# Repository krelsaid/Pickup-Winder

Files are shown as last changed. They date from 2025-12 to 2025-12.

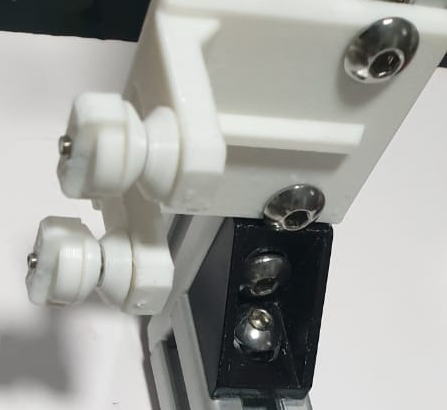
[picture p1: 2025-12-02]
picture/Image 3.png

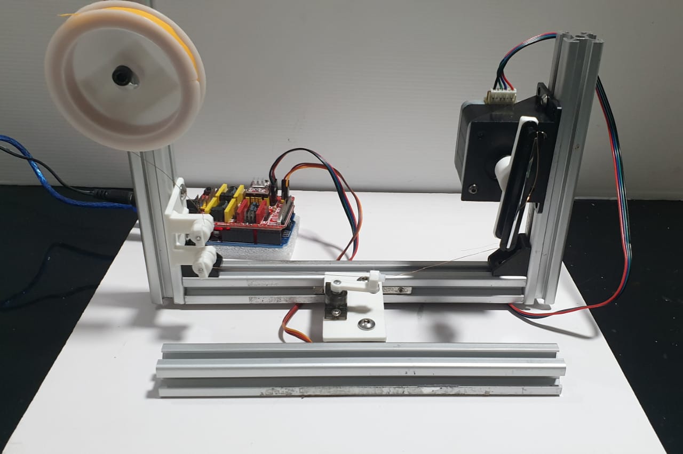
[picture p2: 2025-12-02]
picture/Image 1.jpeg

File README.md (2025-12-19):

# Guitar Pickup Winder Controller

A desktop application for controlling a DIY guitar pickup winder, featuring a real-time visualization of the winding process. Built with Python and PyQt6.

## Table of Contents

- [Overview](#overview)
- [Features](#features)
- [Core Component: The Winder Widget](#core-component-the-winder-widget)
- [How It Works](#how-it-works)
- [Hardware & Firmware Controller (Arduino Uno)](#hardware--firmware-controller-arduino-uno)
- [Dependencies](#dependencies)
- [Setup and Installation](#setup-and-installation)
- [Usage](#usage)
- [Future Development](#future-development)
- [Contributing](#contributing)

## Overview

This project is the software controller for a homemade guitar pickup winder. Winding pickups requires precise control over the number of turns and the distribution of the copper wire across the bobbin. This application provides a graphical user interface (GUI) to:

1.  **Configure** winding parameters (e.g., bobbin dimensions, target turns).
2.  **Control** the winder's motors (stepper for rotation, servo for wire guide).
3.  **Monitor** the winding process in real-time with a detailed visual representation.

The heart of the user interface is the `WinderWidget`, a custom PyQt6 widget that displays a dynamic cross-section of the pickup bobbin as it's being wound.

## Features

- **Graphical User Interface**: Easy-to-use interface built with PyQt6.
- **Real-time Winding Visualization**:
    - Displays a cross-section of the bobbin.
    - Shows the wire guide (servo) position.
    - Visualizes the wire building up in layers.
    - Renders dimension lines for bobbin length and height.
- **Configurable Winding Parameters**:
    - Bobbin Length & Height
    - Wire Diameter
    - Target Number of Turns
    - Turns Per Layer
    - Servo Travel Limits (Min/Max Angle)
- **Live Progress Tracking**: See the current turn count and its relation to the target.
- **Accurate Layer Simulation**: The visualization correctly models the back-and-forth traversal of the wire guide for each layer.

## Core Component: The Winder Widget

The file `winder_widget.py` contains the `WinderWidget` class, which is responsible for all the graphics.

### How it Renders:

1.  **Bobbin**: Draws a brown, T-shaped cross-section representing the bobbin's top and bottom flanges. The drawing is scaled to fit the widget's size.
2.  **Wire Guide**: A cyan line and circle at the top represent the wire guide, which is controlled by a servo. Its horizontal position is calculated based on the winding progress.
3.  **Winding Progress (`pos_ratio`)**: The widget calculates a `pos_ratio` (a value from 0.0 to 1.0) that represents the guide's position across the bobbin. It intelligently determines the direction of travel:
    - On even-numbered layers (0, 2, 4...), it moves from left to right (0.0 → 1.0).
    - On odd-numbered layers (1, 3, 5...), it moves from right to left (1.0 → 0.0).
4.  **Wire Buildup**: As the winding progresses, the widget draws vertical "gold" lines to represent the strands of wire. A new line is added only when the guide has moved a distance equivalent to one wire diameter, creating a realistic depiction of the coil.
5.  **Live Wire**: A single line is drawn from the wire guide down to the bobbin, showing the path of the wire currently being laid.

## How It Works

The application operates on a simple but effective principle:

1.  **User Input**: The user enters the physical characteristics of their pickup bobbin and the desired number of turns into the GUI.
2.  **Calculation**: The software calculates the number of turns that will fit in a single layer (`turns_per_layer`).
3.  **Motor Control**:
    - A **stepper motor** is commanded to turn the bobbin. It counts each rotation.
    - A **servo motor** is used to move the wire guide back and forth across the bobbin's length.
4.  **Synchronization**: The application synchronizes the servo's position with the stepper's turn count. The `pos_ratio` from the widget is mapped to the servo's angular range (`servo_min_angle` to `servo_max_angle`) and sent to the physical controller (e.g., an Arduino or ESP32).
5.  **Feedback**: The `WinderWidget` receives live data (current turns, servo position) from the controller part of the application and updates the display, giving the user immediate visual feedback.

## Hardware & Firmware Controller (Arduino Uno)

The Python application acts as the "brain," but the Arduino Uno is the "muscle," responsible for the real-time control of the motors.

### Role of the Firmware

- **Receives Commands**: Listens for commands sent over the serial port from the Python GUI (e.g., start/stop winding, set parameters).
- **Controls Motors**:
    - **Stepper Motor**: Precisely rotates the pickup bobbin. It uses a library like `AccelStepper` for smooth acceleration and constant speed.
    - **Servo Motor**: Moves the wire guide back and forth. Its position is updated continuously based on the winding progress.
- **Sends Feedback**: Reports the current turn count and status back to the Python application for live monitoring.

### Required Hardware

- **Microcontroller**: Arduino Uno.
- **Stepper Motor Driver**: A4988 or DRV8825. These drivers are ideal for controlling a stepper motor with an Arduino.
- **Stepper Motor**: NEMA 17 is a popular size for this application.
- **Servo Motor**: A standard SG90 micro servo is sufficient, but a more robust metal-gear servo (like an MG996R) is recommended for durability.

### Serial Communication Protocol

A simple text-based protocol is used for communication between the PC and the microcontroller.

**Commands from PC to Arduino (sent from Python):**

- `START:<target_turns>:<servo_min>:<servo_max>`: Starts the winding process.
    - Example: `START:8000:70:100`
- `STOP`: Immediately halts the winding process.
- `RESET`: Resets the turn counter to zero.

**Feedback from Arduino to PC (read by Python):**

- `TURN:<count>`: Reports the current number of turns.
    - Example: `TURN:1234`
- `STATUS:<message>`: Reports the current state.
    - Examples: `STATUS:IDLE`, `STATUS:WINDING`, `STATUS:DONE`

### Firmware Setup

1.  **Install Arduino IDE or PlatformIO**: Choose your preferred development environment.
2.  **Install Libraries**: From the library manager, install:
    - `AccelStepper` (by Mike McCauley)
    - `Servo` (usually built-in)
3.  **Configure Pins**: Open the `.ino` sketch and modify the pin definitions at the top of the file to match your hardware wiring.
4.  **Upload**: Compile and upload the sketch to your microcontroller board.

## Dependencies

This project requires Python 3 and the following library:

- **PyQt6**: For the graphical user interface.

```bash
pip install PyQt6
pip install pyserial
```

The physical winder itself would likely be controlled by a microcontroller (like an Arduino or ESP32) running its own firmware, communicating with this Python application over a serial port.

## Setup and Installation

1.  **Clone the repository:**
    ```bash
    git clone https://github.com/krelsaid/Pickup-Winder.git
    cd pickup-winder
    ```

2.  **Install dependencies:**
    ```bash
    pip install -r requirements.txt
    ```
    *(Note: You may need to create a `requirements.txt` file containing `PyQt6`)*

## Usage

1.  Run the main application file:
    ```bash
    python main_window.py
    ```
    *(Assuming the main entry point is `main_window.py`)*

2.  Connect to the winder hardware via the appropriate serial port in the GUI.
3.  Enter your bobbin and wire specifications in the settings panel.
4.  Set the target number of turns.
5.  Click the "Start Winding" button to begin the process.
6.  Monitor the progress on the visualization widget.

## Future Development

- [ ] Implement serial communication to control an Arduino/ESP32.
- [ ] Add presets for common pickup types (Strat, Tele, P-90, Humbucker).
- [ ] Add scatter winding options for a more "hand-wound" sound.
- [ ] Graph winding tension if a load cell is added to the hardware.
- [ ] Save and load winding job configurations to a file.

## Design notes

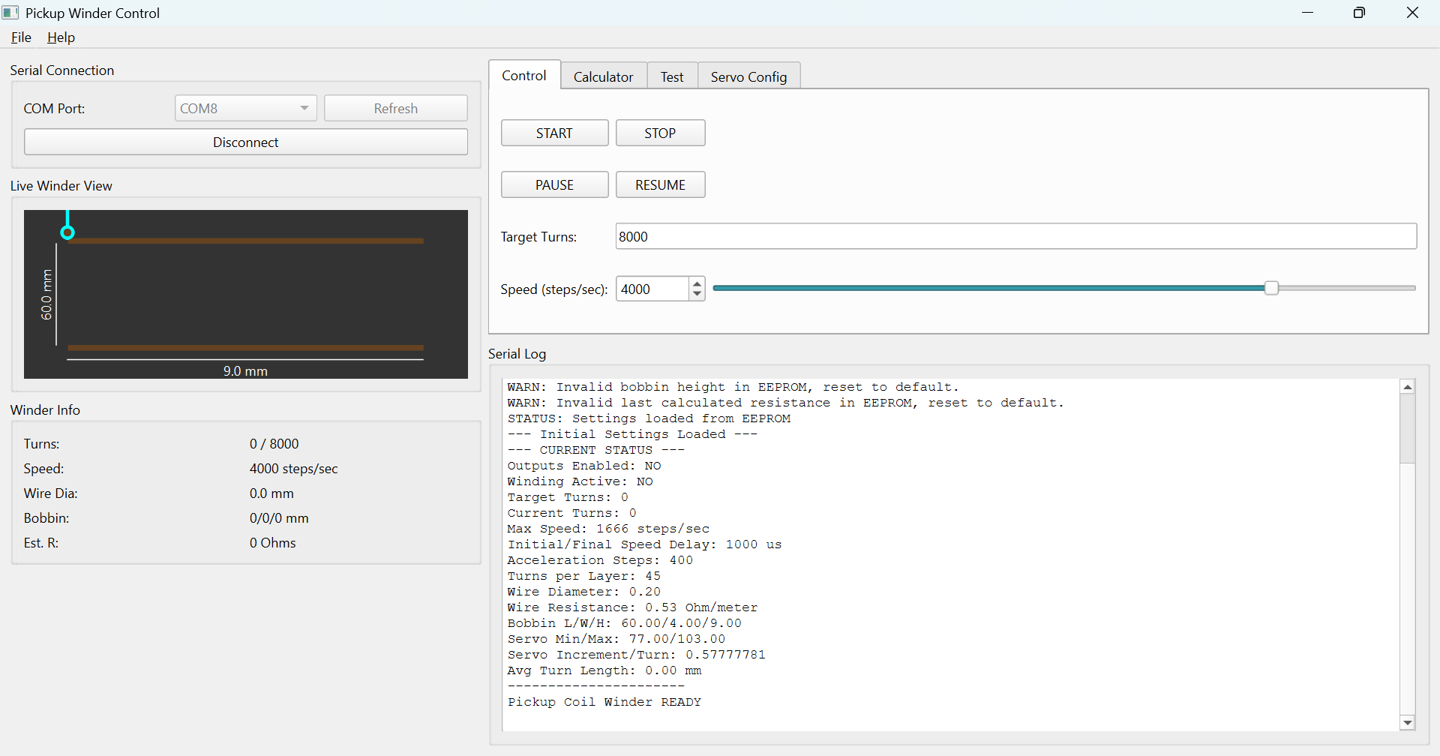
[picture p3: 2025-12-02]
picture/Guitar Pickup Winder Controller GUI.png

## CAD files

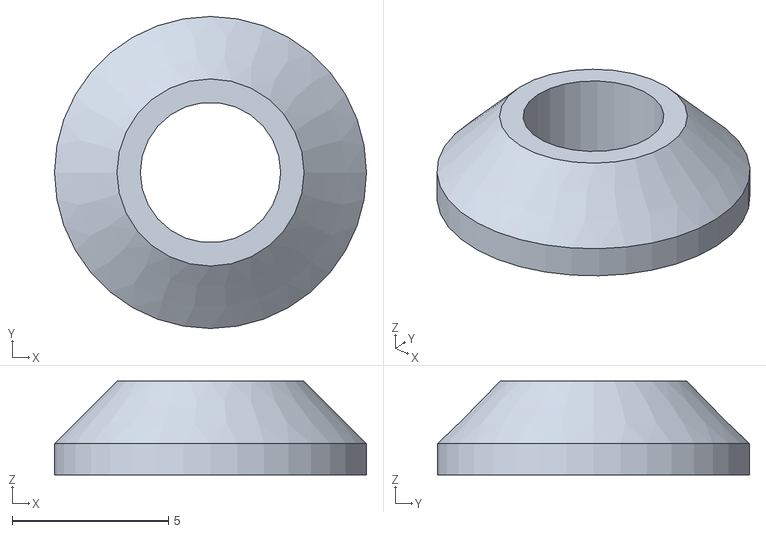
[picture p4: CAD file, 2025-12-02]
stl/spool clamp.stl
10.0 x 10.0 x 3.00

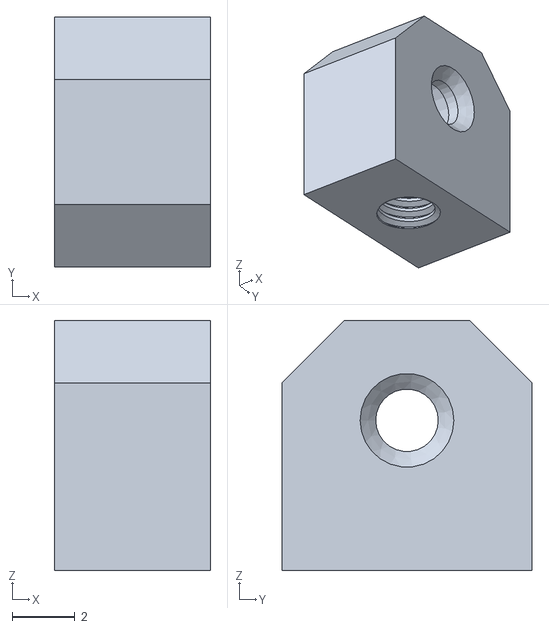
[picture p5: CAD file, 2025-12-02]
stl/lever_head.stl
5.00 x 8.00 x 8.00

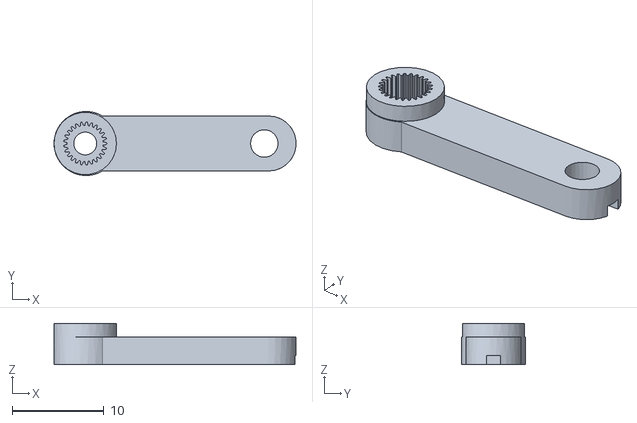
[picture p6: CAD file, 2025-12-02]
stl/servo lever.stl
26.4 x 6.99 x 4.50

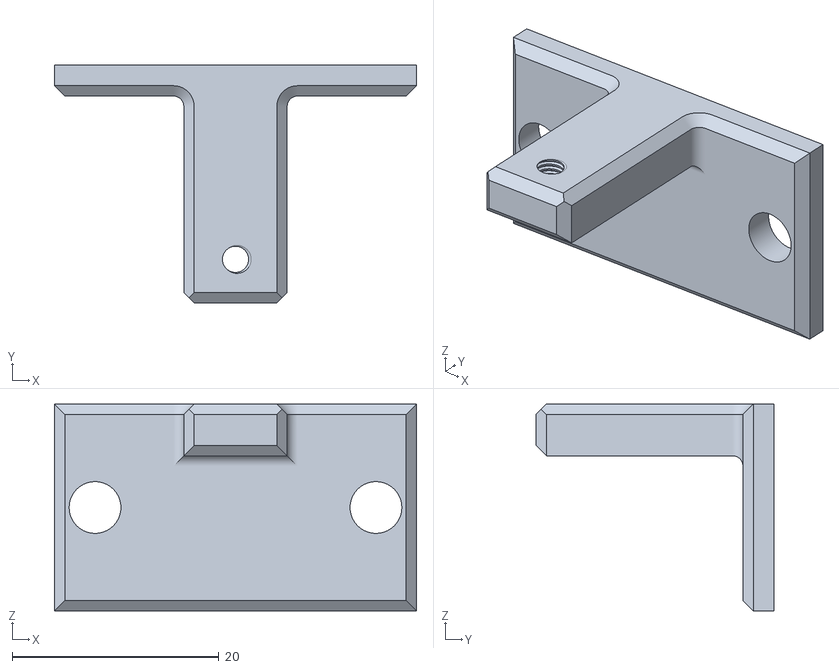
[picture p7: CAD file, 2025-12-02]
stl/spool clamp mount single.stl
35.0 x 23.0 x 20.0

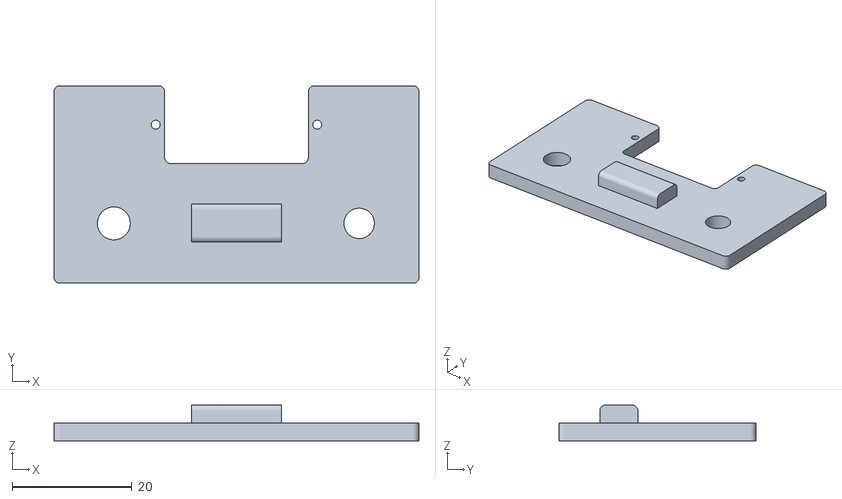
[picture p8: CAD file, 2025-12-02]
stl/servo_mount.stl
61.0 x 33.0 x 6.00

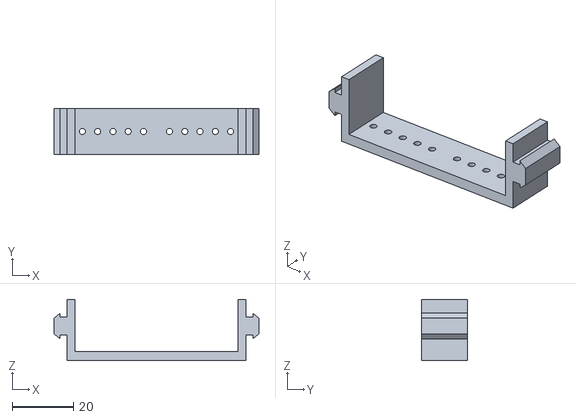
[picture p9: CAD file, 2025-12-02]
stl/winder-board-mount.stl
67.1 x 15.0 x 20.0

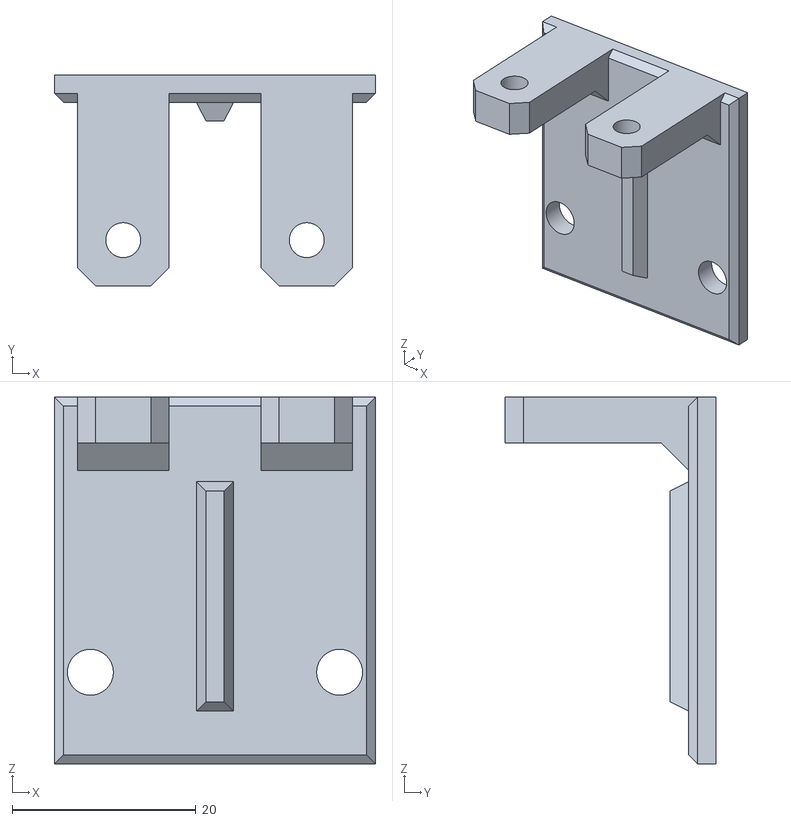
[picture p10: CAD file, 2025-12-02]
stl/spool clamp mount-dual.stl
35.0 x 23.0 x 40.0

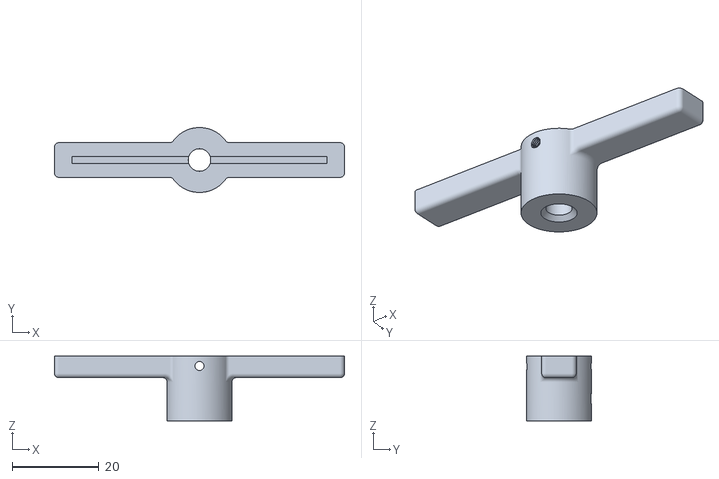
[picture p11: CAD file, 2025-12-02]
stl/bobbin mount.stl
67.0 x 15.0 x 15.0

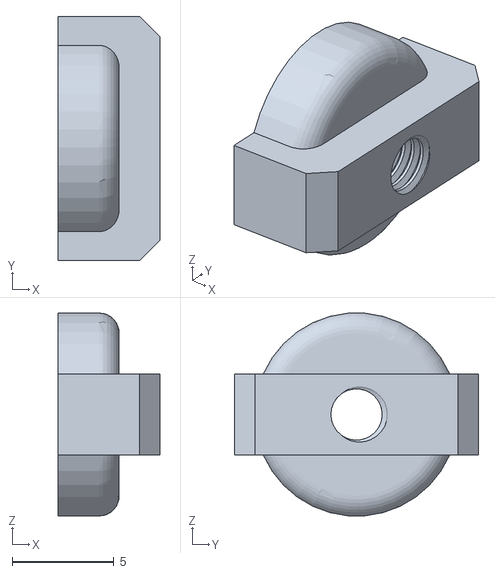
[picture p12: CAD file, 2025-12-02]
stl/clamp nut.stl
5.00 x 12.0 x 9.96

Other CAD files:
stl/bobin_winder-Body.stl

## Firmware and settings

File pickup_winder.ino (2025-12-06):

// Name:    pickup_winder.ino
// Author:  khairil said
// Date:    1/12/2025
// Version: 1.2

#define FIRMWARE_VERSION "1.2.0"

// --- FIRMWARE OVERVIEW ---
// This firmware controls a guitar pickup coil winder using an Arduino and a CNC shield.
//
// Core Components:
// - Stepper Motor (Y-Axis): Manages the main rotation of the winder.
// - Servo Motor: Guides the wire back and forth across the bobbin.
// - Serial Command Interface: All operations are controlled by text-based commands sent
//   over the serial monitor (e.g., START, STOP, PAUSE, BOBBIN, CALC).
//
// Key Features:
// - S-Curve Acceleration: Implements smooth motion for the stepper motor during the
//   first and last rotations to prevent jerking and ensure even winding.
// - Pause/Resume: Winding can be paused and resumed without losing progress.
// - Turn Count Calculation: The 'CALC' command iteratively calculates the required
//   number of turns to achieve a target DC resistance, accounting for the changing
//   bobbin diameter as wire builds up.
// - Dynamic Winding Parameters: Automatically calculates the servo's travel increment
//   per rotation based on bobbin height and wire diameter.
// - EEPROM Storage: Saves all critical settings (servo calibration, speed, acceleration,
//   bobbin dimensions, wire diameter, etc.) so they persist after a power cycle.
// - Comprehensive Testing Suite: Includes commands to test individual components
//   (TEST_SERVO, TEST_STEPPER_MOVE) and winding patterns (TEST_LAYER) without
//   committing to a full wind.
// - Safety Timeout: Automatically disables motors if no command is received for a set
//   period, preventing the machine from being left in an active state.
// - Robust Command Parsing: Commands for setting bobbin dimensions, wire diameter,
//   and other parameters include validation to prevent invalid inputs.

#include <Servo.h>
#include <EEPROM.h>

// -----------------------------
// CNC SHIELD Y-AXIS
// -----------------------------
const int STEP_PIN = 3;
const int DIR_PIN  = 6;
const int EN_PIN   = 8;

// -----------------------------
// SERVO
// -----------------------------
const int SERVO_PIN = 10;
Servo layServo;

// -----------------------------
// SETTINGS
// -----------------------------
long targetTurns = 0;
long currentSteps = 0;
int stepsPerTurn = 3200;       // full-step NEMA17, multiply by microsteps if needed
bool running = false;
bool paused = false;
bool verboseMode = false;

// Stepper direction
bool stepperForward = true;

// Servo calibration / sweep
float servoMinAngle = 70;    
float servoMaxAngle = 100;
float servoPos = servoMinAngle;
float servoIncrementPerTurn = 0.0;

// Pickup & wire
float bobbinHeight = 9.0;      // mm, traversable height between flatwork
float wireDiameter = 0.2;      // mm
long turnsPerLayer = 45;       // calculated
float bobbinLength = 60.0;     // mm, length of the bobbin core
float bobbinWidth = 4.0;       // mm, width/thickness of the bobbin core
float avgTurnLength = 140.0;   // mm, average length of one turn around the bobbin
float lastCalcRequestedResistance = 0.0; // Ohms, stores the last target resistance from CALC command

// Timeout
unsigned long lastCommandTime = 0;
unsigned long timeoutLimit = 10000; // 10s default
bool outputsEnabled = true;

// Acceleration
long stepCount = 0;
long totalSteps = 0;
int initialStepDelay = 1000;      // µs
int minStepDelay = 300;           // µs
long accelSteps = 400;           // steps for accel/decel. A longer ramp prevents jerking.

// Serial input buffer (replaces String object to save memory)
const byte MAX_CMD_LENGTH = 64;
char inputBuffer[MAX_CMD_LENGTH];
byte inputIndex = 0;

// --- Sweep Control ---
// SWEEP_MODE_FIRMWARE: Uses saved servoMin/MaxAngle and calculated turnsPerLayer.
// SWEEP_MODE_GUI:      Expects external 'SERVO POS' commands for each turn.
// SWEEP_MODE_PATTERN:  Uses a temporary pattern sent by the GUI via 'WIND PATTERN'.
enum SweepControlMode { SWEEP_MODE_FIRMWARE, SWEEP_MODE_GUI, SWEEP_MODE_PATTERN };
SweepControlMode sweepControlMode = SWEEP_MODE_FIRMWARE; // Default to firmware-driven sweep

float patternMinAngle = 0.0, patternMaxAngle = 0.0, patternScatter = 0.0;
long patternTurnsPerLayer = 0;

// ==========================
// EEPROM Addresses
// ==========================
int addr = 0;
#define ADDR_SERVO_MIN      (addr)
#define ADDR_SERVO_MAX      (addr += sizeof(float))         // After servo min (float)
#define ADDR_WIRE_DIAM      (addr += sizeof(float))         // After servo max (float)
#define ADDR_STEP_DELAY     (addr += sizeof(float))         // After wire diam (float)
#define ADDR_TIMEOUT        (addr += sizeof(int))           // After step delay (int)
#define ADDR_ACCEL_STEPS    (addr += sizeof(unsigned long)) // After timeout (unsigned long)
#define ADDR_BOBBIN_LEN     (addr += sizeof(long))          // After accel steps (long)
#define ADDR_BOBBIN_WID     (addr += sizeof(float))         // After bobbin len (float)
#define ADDR_BOBBIN_H       (addr += sizeof(float))         // After bobbin wid (float)
#define ADDR_LAST_CALC_R    (addr += sizeof(float))         // After bobbin h (float)
#define ADDR_SWEEP_MODE     (addr += sizeof(float))         // After last calc R (float)
#define EEPROM_SIZE         (addr + sizeof(int))            // Final size after all addresses
// Note: ADDR_STEPS_PER_TURN is not saved/loaded, so it doesn't need an address.
// The next available address would be (addr += sizeof(unsigned long))


// ==========================
// SETUP
// ==========================
void setup() {
  Serial.begin(115200);

  pinMode(STEP_PIN, OUTPUT);
  pinMode(DIR_PIN, OUTPUT);
  pinMode(EN_PIN, OUTPUT);

  // Start with outputs disabled for safety.
  // enableOutputs() will attach the servo when needed.
  digitalWrite(EN_PIN, HIGH);
  outputsEnabled = false;
  
  loadSettings();             // Load from EEPROM
  computeWindingParameters(); // Initial calculation with loaded/default values

  Serial.println(F("\n--- Initial Settings Loaded ---"));
  printStatus();

  Serial.println(F("Pickup Coil Winder READY"));
}

// ==========================
// ENABLE / DISABLE OUTPUTS
// ==========================
void enableOutputs() {
  digitalWrite(EN_PIN, LOW); // enable stepper
  if (!layServo.attached()) { layServo.attach(SERVO_PIN); delay(50); } // Add small delay for servo to initialize
  outputsEnabled = true;
  Serial.println(F("STATUS: Outputs ENABLED"));
}

void disableOutputs() {
  digitalWrite(EN_PIN, HIGH); // disable stepper
  if (layServo.attached()) layServo.detach();
  outputsEnabled = false;
  Serial.println(F("STATUS: Outputs DISABLED"));
}

// ==========================
// ENABLE / DISABLE SERVO ONLY
// ==========================
void enableServo() {
  if (!layServo.attached()) { 
    layServo.attach(SERVO_PIN); 
    delay(50); // Add small delay for servo to initialize
  }
}

void disableServo() {
  if (layServo.attached()) layServo.detach();
}

// ==========================
// COMPUTE SERVO INCREMENT
// ==========================
void updateAndValidate() {
  // Re-run sanity checks on values that might have been changed by commands
  bool anglesInvalid = false;
  if (isnan(servoMinAngle) || servoMinAngle < 0 || servoMinAngle > 180 || servoMinAngle >= servoMaxAngle) {
    servoMinAngle = 77.0;
    anglesInvalid = true;
  }
  if (isnan(servoMaxAngle) || servoMaxAngle < 0 || servoMaxAngle > 180 || servoMinAngle >= servoMaxAngle) {
    servoMaxAngle = 103.0;
    anglesInvalid = true;
  }
  if (anglesInvalid) Serial.println(F("WARN: Invalid servo angles detected, resetting to defaults."));

  if (isnan(wireDiameter) || wireDiameter <= 0.0) {
    wireDiameter = 0.2; // Reset to a safe default
    Serial.println(F("WARN: Invalid wire diameter detected, resetting to default."));
  }

  // Now that values are safe, perform the calculation
  computeWindingParameters();
}

void computeWindingParameters() {
  if (wireDiameter > 0) turnsPerLayer = (long)(bobbinHeight / wireDiameter);
  servoPos = servoMinAngle;
}

// ==========================
// SERVO POSITIONING
// ==========================
void updateServoPosition(long currentStepCount, long totalTurnsInLayer, float minAngle, float maxAngle, float scatterPercent) {
  long currentTurn = currentStepCount / stepsPerTurn;
  long layer = currentTurn / totalTurnsInLayer;
  long turnInLayer = currentTurn % totalTurnsInLayer;

  // Apply scatter to create a margin
  float angleRange = maxAngle - minAngle;
  float scatterAmount = angleRange * (scatterPercent / 100.0);
  float effectiveMin = minAngle + (scatterAmount / 2.0);
  float effectiveMax = maxAngle - (scatterAmount / 2.0);

  // If there's only one turn (or less) per layer, the servo doesn't need to move.
  // Position it at the start of the current layer's direction.
  if (totalTurnsInLayer <= 1) {
    servoPos = (layer % 2 == 0) ? effectiveMin : effectiveMax;
    layServo.write((int)servoPos);
    return;
  }

  // Calculate the total angular distance the servo needs to travel for one layer.
  float sweepRange = effectiveMax - effectiveMin;

  // Calculate the small angle change required for each turn (the "pitch").
  // We divide by (totalTurnsInLayer - 1) because N turns create N-1 intervals of movement.
  float pitchAngle = sweepRange / (float)(totalTurnsInLayer - 1);
  
  if (layer % 2 == 0) { // Even layers (0, 2, 4...): move from effective min to max
    servoPos = effectiveMin + (turnInLayer * pitchAngle);
  } else { // Odd layers (1, 3, 5...): move from effective max to min
    servoPos = effectiveMax - (turnInLayer * pitchAngle);
  }
  layServo.write((int)servoPos);
}

// ==========================
// TIMEOUT CHECK
// ==========================
void checkTimeout() {
  if (millis() - lastCommandTime > timeoutLimit) {
    if (outputsEnabled) {
      disableOutputs();
      running = false;
      Serial.println(F("STATUS: AUTO-TIMEOUT - Outputs disabled"));
    }
  }
}

// ==========================
// EEPROM FUNCTIONS
// ==========================
void saveSettings() {
  EEPROM.put(ADDR_SERVO_MIN, servoMinAngle);
  EEPROM.put(ADDR_SERVO_MAX, servoMaxAngle);
  EEPROM.put(ADDR_WIRE_DIAM, wireDiameter);
  EEPROM.put(ADDR_STEP_DELAY, initialStepDelay);
  EEPROM.put(ADDR_TIMEOUT, timeoutLimit);
  EEPROM.put(ADDR_ACCEL_STEPS, accelSteps);
  EEPROM.put(ADDR_BOBBIN_LEN, bobbinLength);
  EEPROM.put(ADDR_BOBBIN_WID, bobbinWidth);
  EEPROM.put(ADDR_BOBBIN_H, bobbinHeight);
  EEPROM.put(ADDR_LAST_CALC_R, lastCalcRequestedResistance);
  EEPROM.put(ADDR_SWEEP_MODE, (int)sweepControlMode);
  Serial.println(F("STATUS: Settings saved to EEPROM"));
}

void clearEEPROM() {
  Serial.println(F("INFO: Clearing EEPROM..."));
  for (int i = 0; i < EEPROM_SIZE; i++) {
    EEPROM.write(i, 0xFF); // Write 0xFF to each byte, which is an invalid state for floats
  }
  Serial.println(F("STATUS: EEPROM cleared."));
}

void loadSettings() {
  EEPROM.get(ADDR_SERVO_MIN, servoMinAngle);
  EEPROM.get(ADDR_SERVO_MAX, servoMaxAngle);
  EEPROM.get(ADDR_WIRE_DIAM, wireDiameter);
  EEPROM.get(ADDR_STEP_DELAY, initialStepDelay);
  EEPROM.get(ADDR_TIMEOUT, timeoutLimit);
  EEPROM.get(ADDR_ACCEL_STEPS, accelSteps);
  EEPROM.get(ADDR_BOBBIN_LEN, bobbinLength);
  EEPROM.get(ADDR_BOBBIN_WID, bobbinWidth);
  EEPROM.get(ADDR_BOBBIN_H, bobbinHeight);
  EEPROM.get(ADDR_LAST_CALC_R, lastCalcRequestedResistance);
  EEPROM.get(ADDR_SWEEP_MODE, (int&)sweepControlMode);

  // --- Sanity Checks for all loaded values ---

  // Check servo angles
  bool servoAnglesInvalid = false;
  if (isnan(servoMinAngle) || servoMinAngle < 0 || servoMinAngle > 180) {
    servoMinAngle = 77.0; // Default value
    servoAnglesInvalid = true;
  }
  if (isnan(servoMaxAngle) || servoMaxAngle < 0 || servoMaxAngle > 180) {
    servoMaxAngle = 103.0; // Default value
    servoAnglesInvalid = true;
  }
  if (servoMinAngle >= servoMaxAngle) {
    servoMinAngle = 77.0;
    servoMaxAngle = 103.0;
    servoAnglesInvalid = true;
  }
  if (servoAnglesInvalid) {
    Serial.println(F("WARN: Invalid servo angles in EEPROM, reset to defaults."));
  }

  // Check wire diameter
  if (isnan(wireDiameter) || wireDiameter <= 0.0) {
    wireDiameter = 0.2; // Reset to a safe default
    Serial.println(F("WARN: Invalid wire diameter in EEPROM, reset to default."));
  }

  // Check step delay (speed)
  if (initialStepDelay <= minStepDelay || initialStepDelay > 20000) {
    initialStepDelay = 1000; // Reset to a safe default
    Serial.println(F("WARN: Invalid step delay in EEPROM, reset to default."));
  }

  // Check timeout limit
  if (timeoutLimit < 1000) { // Must be at least 1 second
    timeoutLimit = 10000; // Reset to default
    Serial.println(F("WARN: Invalid timeout in EEPROM, reset to default."));
  }

  // Check acceleration steps
  if (accelSteps <= 0 || accelSteps > 10000) {
    accelSteps = 400; // Reset to a safe default
    Serial.println(F("WARN: Invalid accel steps in EEPROM, reset to default."));
  }

  // Check bobbin dimensions
  if (isnan(bobbinLength) || bobbinLength <= 0.0 || bobbinLength > 1000.0) {
    bobbinLength = 60.0;
    Serial.println(F("WARN: Invalid bobbin length in EEPROM, reset to default."));
  }
  if (isnan(bobbinWidth) || bobbinWidth <= 0.0 || bobbinWidth > 1000.0) {
    bobbinWidth = 4.0;
    Serial.println(F("WARN: Invalid bobbin width in EEPROM, reset to default."));
  }
  if (isnan(bobbinHeight) || bobbinHeight <= 0.0 || bobbinHeight > 100.0) {
    bobbinHeight = 9.0;
    Serial.println(F("WARN: Invalid bobbin height in EEPROM, reset to default."));
  }
  // Check lastCalcRequestedResistance
  if (isnan(lastCalcRequestedResistance) || lastCalcRequestedResistance < 0.0) {
    lastCalcRequestedResistance = 0.0;
    Serial.println(F("WARN: Invalid last calculated resistance in EEPROM, reset to default."));
  }

  // Check sweep control mode
  if (sweepControlMode != SWEEP_MODE_FIRMWARE && sweepControlMode != SWEEP_MODE_GUI) {
    sweepControlMode = SWEEP_MODE_FIRMWARE; // Default to firmware calculation
    Serial.println(F("WARN: Invalid sweep control mode in EEPROM, reset to default."));
  }

  Serial.println(F("STATUS: Settings loaded from EEPROM"));

  // Calculate avgTurnLength from loaded bobbin dimensions
  calculateAvgTurnLength();
}

// ==========================
// S-CURVE DELAY CALCULATION
// ==========================
int calculateSCurveDelay(long currentStepInRamp, long totalRampSteps) {
  // Uses a cosine function to create a smooth S-curve for acceleration/deceleration.
  float cos_input = (float)currentStepInRamp / totalRampSteps;
  float cos_output = cos(cos_input * PI); // cos() goes from 1 to -1 as input goes from 0 to PI
  float multiplier = (1.0 - cos_output) / 2.0; // Scale to a 0.0 to 1.0 range

  int delayRange = initialStepDelay - minStepDelay;
  return initialStepDelay - (int)(delayRange * multiplier);
}

// ==========================
// ACCELERATED STEP FUNCTION
// ==========================
int stepWithAcceleration() {
  // This function now applies accel/decel only on the first and last rotations.
  int delayNow;
  long currentTurn = stepCount / stepsPerTurn; // Which rotation are we on?
  long stepsIntoTurn = stepCount % stepsPerTurn; // How many steps into the current rotation?

  if(currentTurn == 0 && stepsIntoTurn < accelSteps) {
    // ACCELERATE: Only on the first part of the first rotation
    delayNow = calculateSCurveDelay(stepsIntoTurn, accelSteps);
  } 
  else if(currentTurn == (targetTurns - 1) && stepsIntoTurn >= (stepsPerTurn - accelSteps)) {
    // DECELERATE: Only on the last part of the last rotation
    long decelStepCount = stepsIntoTurn - (stepsPerTurn - accelSteps);
    delayNow = calculateSCurveDelay(accelSteps - decelStepCount, accelSteps);
  } 
  else {
    // CONSTANT SPEED
    delayNow = minStepDelay;
  }

  // Ensure delay doesn't go below the minimum
  if (delayNow < minStepDelay) delayNow = minStepDelay;

  digitalWrite(STEP_PIN, HIGH);
  delayMicroseconds(delayNow);
  digitalWrite(STEP_PIN, LOW);
  delayMicroseconds(delayNow);

  stepCount++;

  return delayNow;
}

void calculateAvgTurnLength() {
  if (bobbinLength <= 0 || bobbinWidth <= 0 || wireDiameter <= 0 || targetTurns <= 0) {
    avgTurnLength = 0; // Not enough info to calculate
    return;
  }

  // Calculate the perimeter of the core (first turn)
  float corePerimeter = (2 * bobbinLength) + (PI * bobbinWidth);

  // Estimate the thickness of the wire winding on one side
  long turnsPerLayerNow = (long)(bobbinHeight / wireDiameter);
  if (turnsPerLayerNow <= 0) turnsPerLayerNow = 1;
  float totalLayers = (float)targetTurns / turnsPerLayerNow;
  float windingThickness = totalLayers * wireDiameter;

  // Calculate the perimeter of the fully wound coil (last turn)
  float finalPerimeter = (2 * bobbinLength) + (PI * (bobbinWidth + 2 * windingThickness));
  avgTurnLength = (corePerimeter + finalPerimeter) / 2.0;
}

bool checkSerial() {
  // More memory-efficient serial reading
  while (Serial.available() > 0) {
    char c = Serial.read();
    if (c == '\n' || c == '\r') { // Handle newline or carriage return
      if (inputIndex > 0) {
        inputBuffer[inputIndex] = '\0'; // Null-terminate the string
        inputIndex = 0; // Reset for next command
        return true; // Command is ready
      }
    } else if (inputIndex < (MAX_CMD_LENGTH - 1)) {
      // Convert command to uppercase as it's typed
      inputBuffer[inputIndex++] = toupper(c);
    }
  }
  return false; // No command ready
}
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
void loop() {
  if (checkSerial()) {
    processCommand(inputBuffer);
  }

  checkTimeout();

  if(running && outputsEnabled && stepCount < totalSteps){
    // This loop is now non-blocking because the main winding logic is handled one step at a time per main loop() iteration.
    if(running && outputsEnabled){
      int currentDelay = stepWithAcceleration();

      // Print status for every completed turn if in verbose mode
      if (verboseMode && stepCount > 0 && stepCount % stepsPerTurn == 0) {
        long currentTurn = stepCount / stepsPerTurn;
        Serial.print(F("  -> Turn: "));
        Serial.print(currentTurn);
        Serial.print(F(" | Servo Pos: "));
        Serial.println(servoPos);
      }
      
      // Only run internal sweep logic if in FIRMWARE mode
      if (stepCount > 0 && stepCount % stepsPerTurn == 0) {
          if (sweepControlMode == SWEEP_MODE_FIRMWARE) {
              updateServoPosition(stepCount, turnsPerLayer, servoMinAngle, servoMaxAngle, 0); // 0 scatter for default firmware mode
          } else if (sweepControlMode == SWEEP_MODE_PATTERN) {
              updateServoPosition(stepCount, patternTurnsPerLayer, patternMinAngle, patternMaxAngle, patternScatter);
          }
      }
    }
    
    if(stepCount >= totalSteps){ 
      running=false; 
      verboseMode = false; // Disable verbose mode on completion
      Serial.println(F("STATUS: Winding completed.")); 
      disableOutputs(); 
    }    
  }
}

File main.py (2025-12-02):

# Name:     pickup winder control GUI
# Author:   khairil said
# Date:     12/2/2025
# Version:  1.0

import sys
import logging
from PyQt6.QtWidgets import QApplication
from gui import MainWindow
from logging_config import setup_logging

if __name__ == '__main__':
    # Setup logging as the very first thing
    setup_logging()
    logging.info("Application starting up...")

    # Create the application instance
    app = QApplication(sys.argv)
    
    # Set a modern style for the UI
    app.setStyle("Fusion")
    
    # Create and show the main window
    window = MainWindow()
    window.show()
    
    # Start the event loop
    exit_code = app.exec()
    logging.info(f"Application exiting with code {exit_code}.")
    sys.exit(exit_code)
